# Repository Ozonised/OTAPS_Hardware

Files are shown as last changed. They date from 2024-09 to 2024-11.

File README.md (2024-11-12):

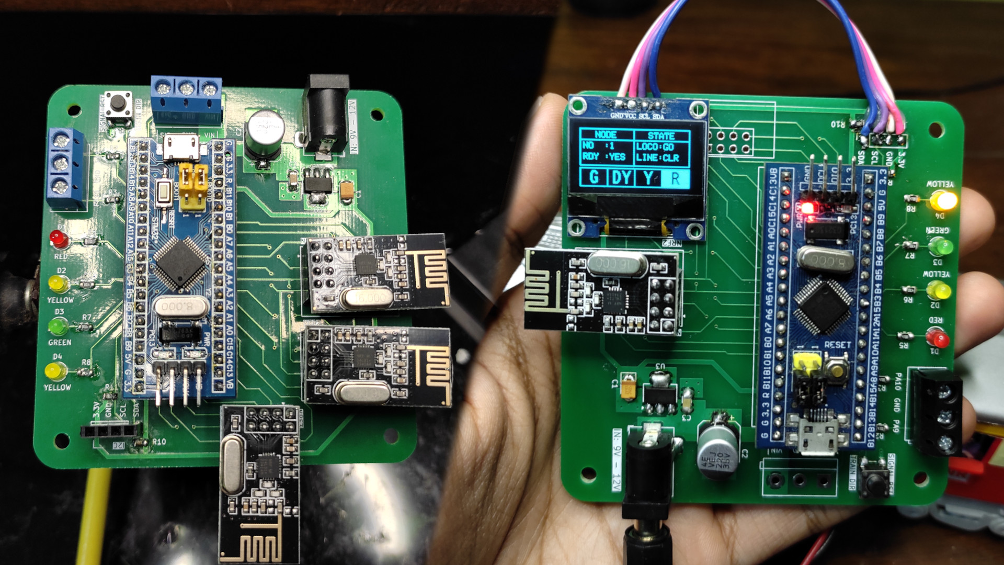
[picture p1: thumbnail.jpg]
thumbnail

# OTAPS - Open Train Accident Prevention System
This repository contains schematic, PCB and wiring files for OTAPS.

## Directory info:
1. ```Wiring``` contains the schematic for wiring signal node.
2. ```WiringLocomotiveUnit``` contains the schematic for wiring the locomotive unit.
3. ```Nodes``` contains the schematic and PCBs files for the PCBs.

# DETAILS:
I created this project for the **Circuit Digest 2024 IoT & Edge AI Project Challenge**.
The firmware for the signal and locomotive units is available at this repository: https://github.com/Ozonised/OTAPS_Firmware
The project details including features, working protocol, build guide and code explanation can be found on this page: https://circuitdigest.com/microcontroller-projects/otaps-open-train-accident-prevention-system

### NOTE:
Both signal and locomotive units utilise the same PCB.

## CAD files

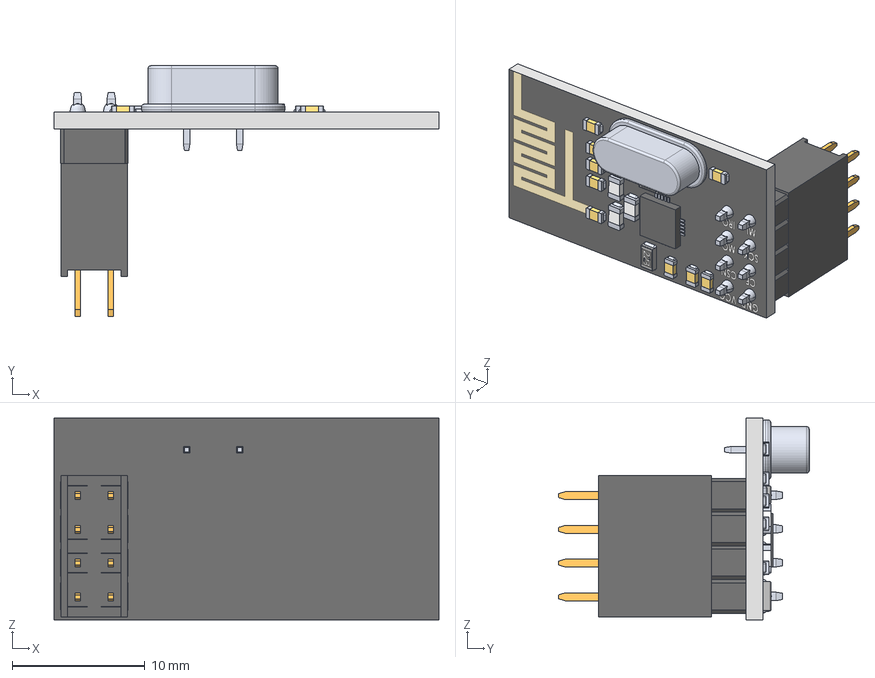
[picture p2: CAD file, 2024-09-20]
Nodes/3D_Models/NRF24L10 with female header-Assembly.step
29.0 x 18.9 x 15.2 mm
nrfboard
CrystalOscillator
doubleMaleHeader x 4
solder x 8
1.7mmSmdCeramicCapacitor x 9
1.7mmSmdCeramicCapacitor001 x 9
1.7mmSmdCeramicCapacitor002 x 9
smdResistor223
smdResistor224
smdResistor225
smdResistor105
smdResistor227
smdResistor228
smdceramiccapacitorwhite x 3
smdceramiccapacitorwhite001 x 3
smdceramiccapacitorwhite002 x 3
4x4SMDchip
4x4SMDchip001
4x4SMDchip002
4x4SMDchip003
4x4SMDchip004
4x4SMDchip005
4x4SMDchip006
4x4SMDchip007
4x4SMDchip008
4x4SMDchip009
4x4SMDchip010
4x4SMDchip011
4x4SMDchip012
4x4SMDchip013
4x4SMDchip014
4x4SMDchip015
4x4SMDchip016
4x4SMDchip017
4x4SMDchip018
4x4SMDchip019
4x4SMDchip020

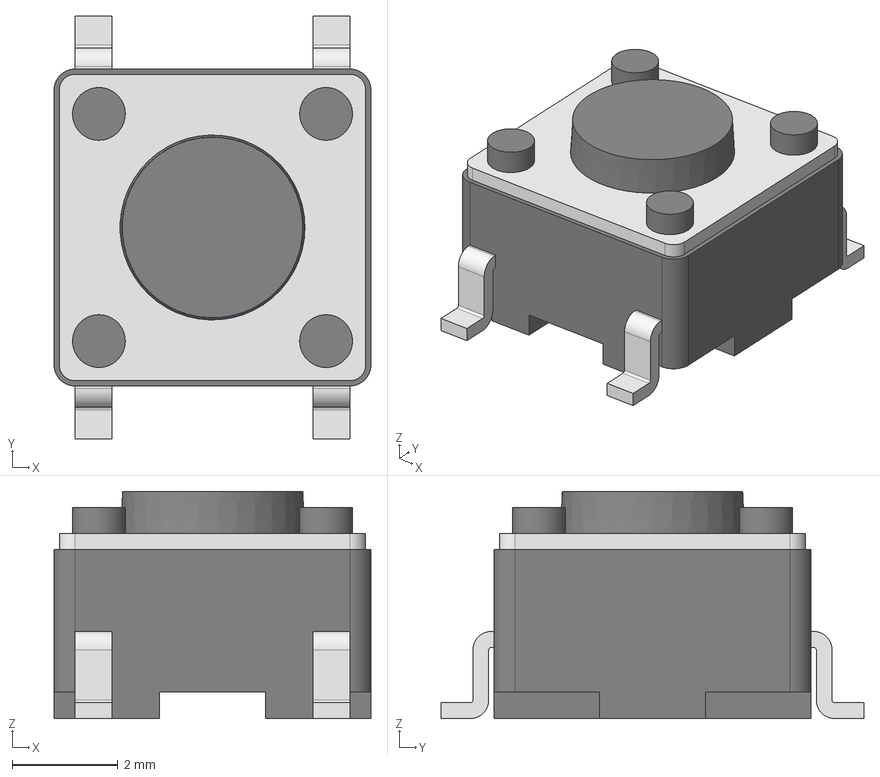
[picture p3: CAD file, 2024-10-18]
Nodes/3D_Models/button_smd_6x6x4.3.stp
6.00 x 8.00 x 4.30 mm

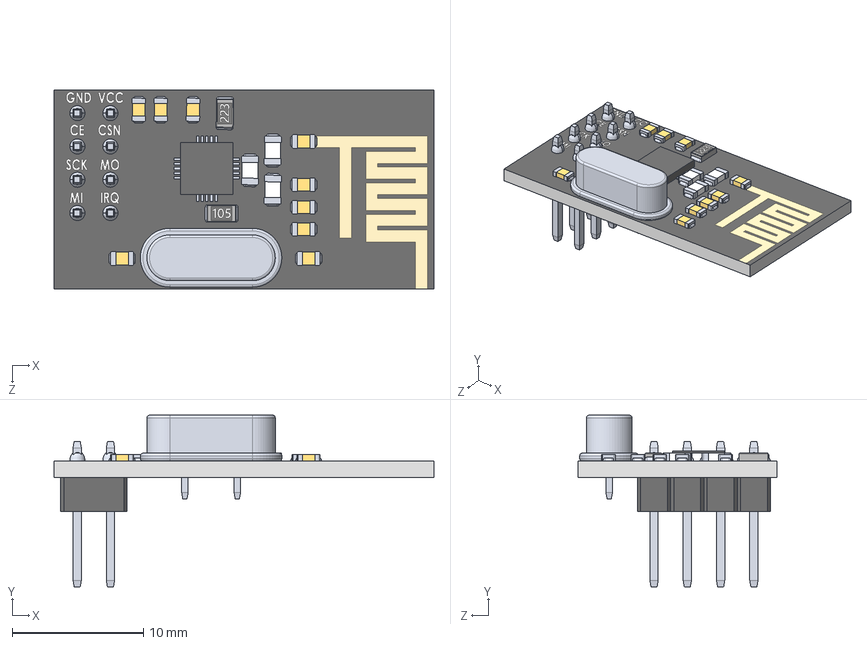
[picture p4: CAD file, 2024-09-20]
Nodes/NRF24/Wireless Radio Transmitter and Receiver nRF24L01.STEP
29.0 x 13.1 x 15.2 mm
nrfboard
CrystalOscillator
doubleMaleHeader x 4
solder x 8
1.7mmSmdCeramicCapacitor x 9
smdResistor223
smdResistor105
smdceramiccapacitorwhite x 3
4x4SMDchip

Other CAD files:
Nodes/3D_Models/3 PIN DG306-5 BLUE - PITCH 5 mm.stp

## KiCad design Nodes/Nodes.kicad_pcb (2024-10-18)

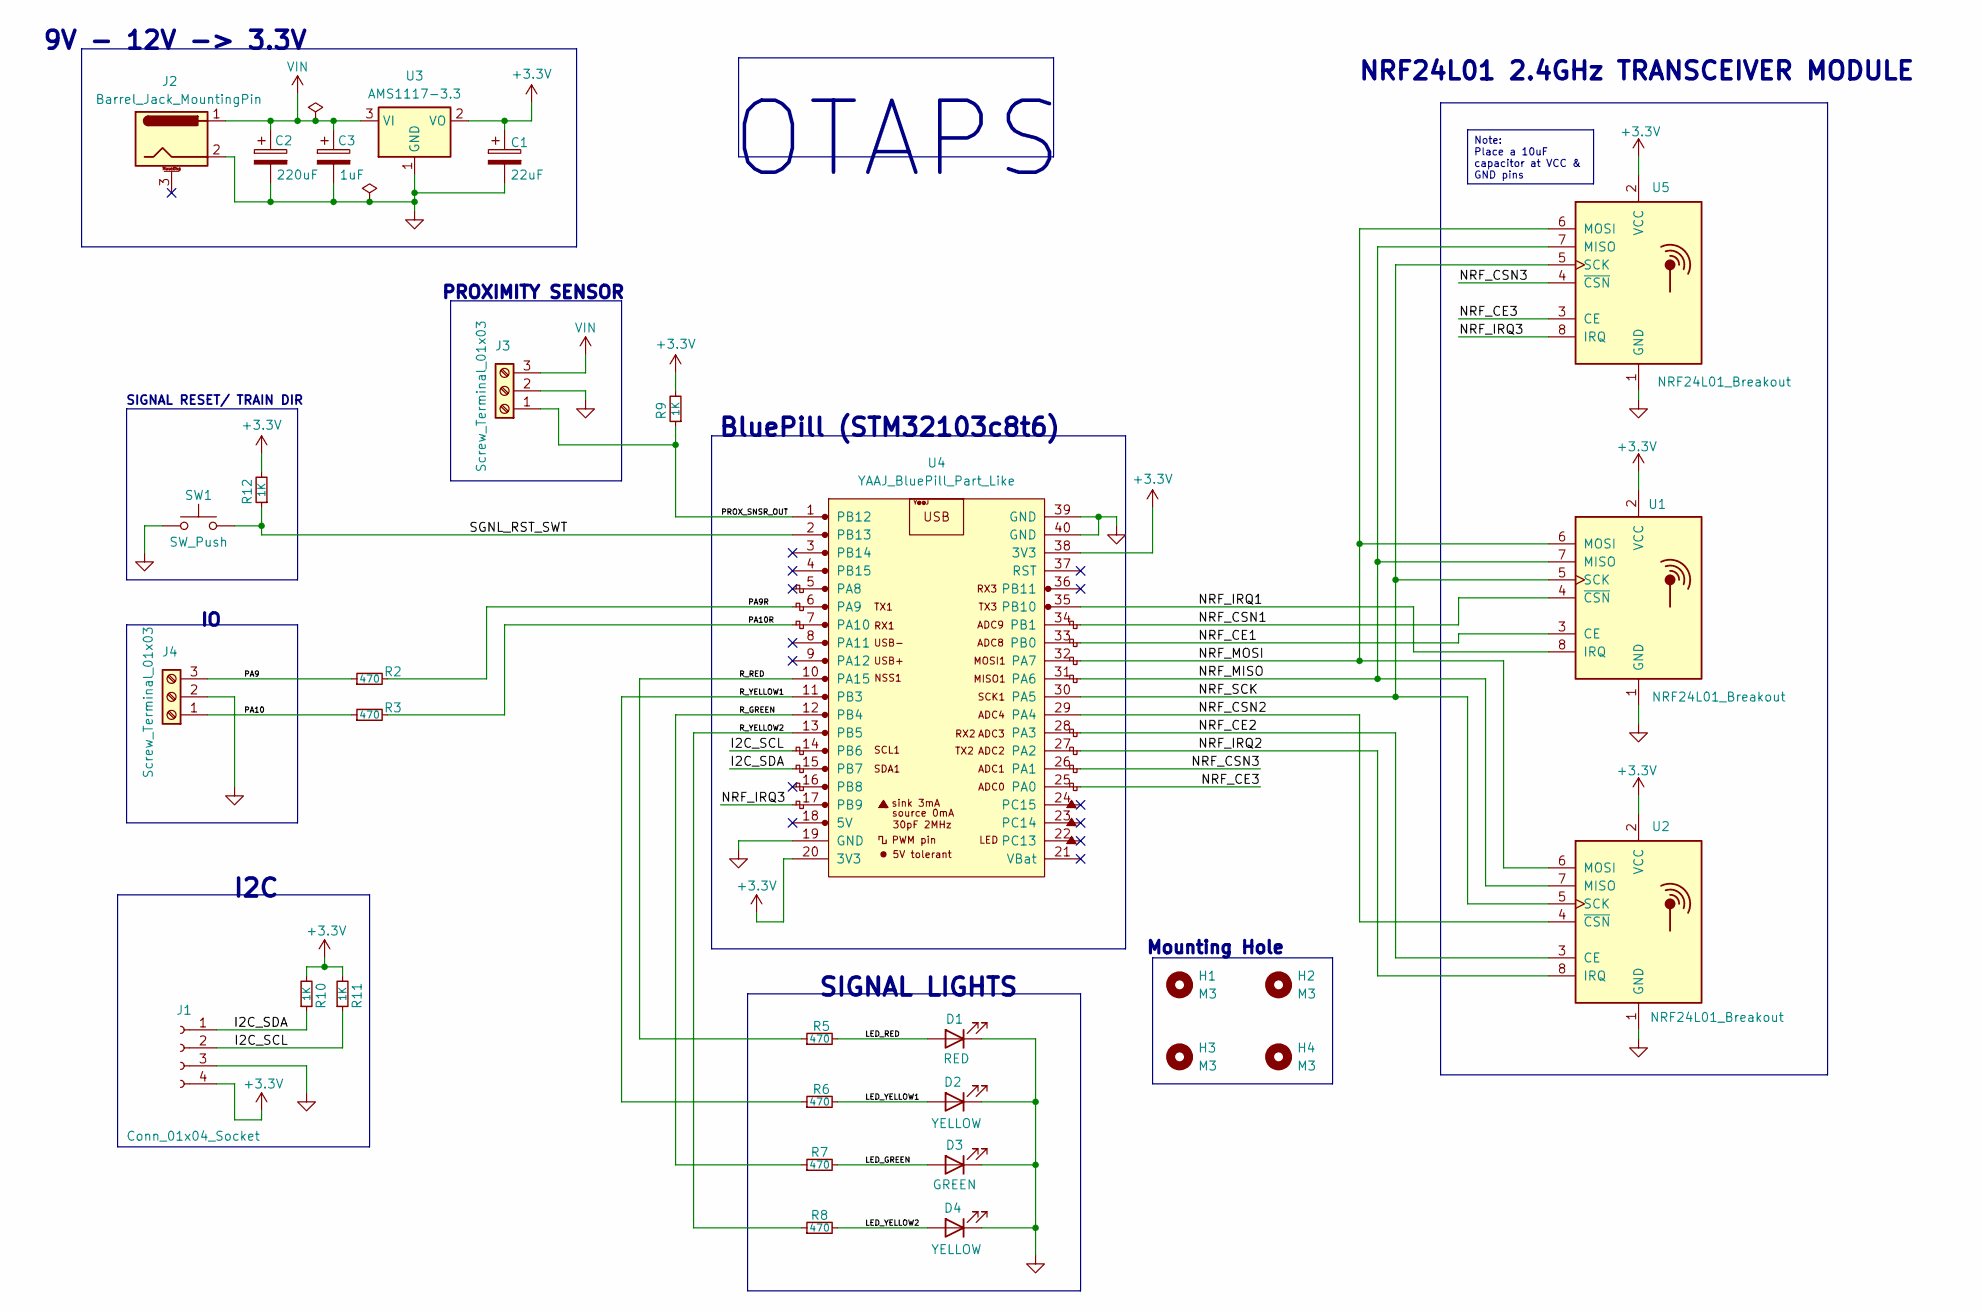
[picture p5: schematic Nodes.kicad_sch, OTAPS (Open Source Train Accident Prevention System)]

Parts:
C1: 22uF; CP_EIA-3528-15_AVX-H_Pad1.50x2.35mm_HandSolder
C2: 220uF; CP_Elec_8x10.5
C3: 1uF; C_1206_3216Metric_Pad1.33x1.80mm_HandSolder
D1: RED; LED_D3.0mm
D2, D4: YELLOW; LED_D3.0mm
D3: GREEN; LED_D3.0mm
H1, H2, H3, H4: M3; MountingHole_3.2mm_M3
J1: Conn_01x04_Socket; PinSocket_1x04_P2.54mm_Vertical
J2: Barrel_Jack_MountingPin; BarrelJack_Horizontal
J3, J4: Screw_Terminal_01x03
R2, R3, R5, R6, R7, R8: 470; R_0805_2012Metric_Pad1.20x1.40mm_HandSolder
R9, R10, R11, R12: 1K; R_0805_2012Metric_Pad1.20x1.40mm_HandSolder
SW1: SW_Push; SW_SPST_PTS647_Sx38
U1, U2, U5: NRF24L01_Breakout; nRF24L01_Breakout
U3: AMS1117-3.3; SOT-223-3_TabPin2
U4: YAAJ_BluePill_Part_Like; YAAJ_BluePill_1

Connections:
+3.3V: C1.1, J1.4, R9.2, R10.2, R11.2, R12.2, U1.2 (VCC), U2.2 (VCC), U3.2 (VO), U4.20 (3V3), U4.38 (3V3), U5.2 (VCC)
/I2C_SCL: J1.2, R11.1, U4.14 (PB6)
/I2C_SDA: J1.1, R10.1, U4.15 (PB7)
/LED_GREEN: D3.2 (A), R7.2
/LED_RED: D1.2 (A), R5.2
/LED_YELLOW1: D2.2 (A), R6.2
/LED_YELLOW2: D4.2 (A), R8.2
/NRF_CE1: U1.3 (CE), U4.33 (PB0)
/NRF_CE2: U2.3 (CE), U4.28 (PA3)
/NRF_CE3: U4.25 (PA0), U5.3 (CE)
/NRF_CSN1: U1.4 (~CSN), U4.34 (PB1)
/NRF_CSN2: U2.4 (~CSN), U4.29 (PA4)
/NRF_CSN3: U4.26 (PA1), U5.4 (~CSN)
/NRF_IRQ1: U1.8 (IRQ), U4.35 (PB10)
/NRF_IRQ2: U2.8 (IRQ), U4.27 (PA2)
/NRF_IRQ3: U4.17 (PB9), U5.8 (IRQ)
/NRF_MISO: U1.7 (MISO), U2.7 (MISO), U4.31 (PA6), U5.7 (MISO)
/NRF_MOSI: U1.6 (MOSI), U2.6 (MOSI), U4.32 (PA7), U5.6 (MOSI)
/NRF_SCK: U1.5 (SCK), U2.5 (SCK), U4.30 (PA5), U5.5 (SCK)
/PA9: J4.3, R2.1
/PA9R: R2.2, U4.6 (PA9)
/PA10: J4.1, R3.1
/PA10R: R3.2, U4.7 (PA10)
/PROX_SNSR_OUT: J3.1, R9.1, U4.1 (PB12)
/R_GREEN: R7.1, U4.12 (PB4)
/R_RED: R5.1, U4.10 (PA15)
/R_YELLOW1: R6.1, U4.11 (PB3)
/R_YELLOW2: R8.1, U4.13 (PB5)
/SGNL_RST_SWT: R12.1, SW1.2, U4.2 (PB13)
GND: C1.2, C2.2, C3.2, D1.1 (K), D2.1 (K), D3.1 (K), D4.1 (K), J1.3, J2.2, J3.2, J4.2, SW1.1, U1.1 (GND), U2.1 (GND), U3.1 (GND), U4.19 (GND), U4.39 (GND), U4.40 (GND), U5.1 (GND)
VIN: C2.1, C3.1, J2.1, J3.3, U3.3 (VI)

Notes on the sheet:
Note: Place a 10uF capacitor at VCC & GND pins
NRF24L01 2.4GHz TRANSCEIVER MODULE
SIGNAL LIGHTS
9V - 12V -> 3.3V
I2C
BluePill (STM32103c8t6)
OTAPS
Mounting Hole
PROXIMITY SENSOR
SIGNAL RESET/ TRAIN DIR

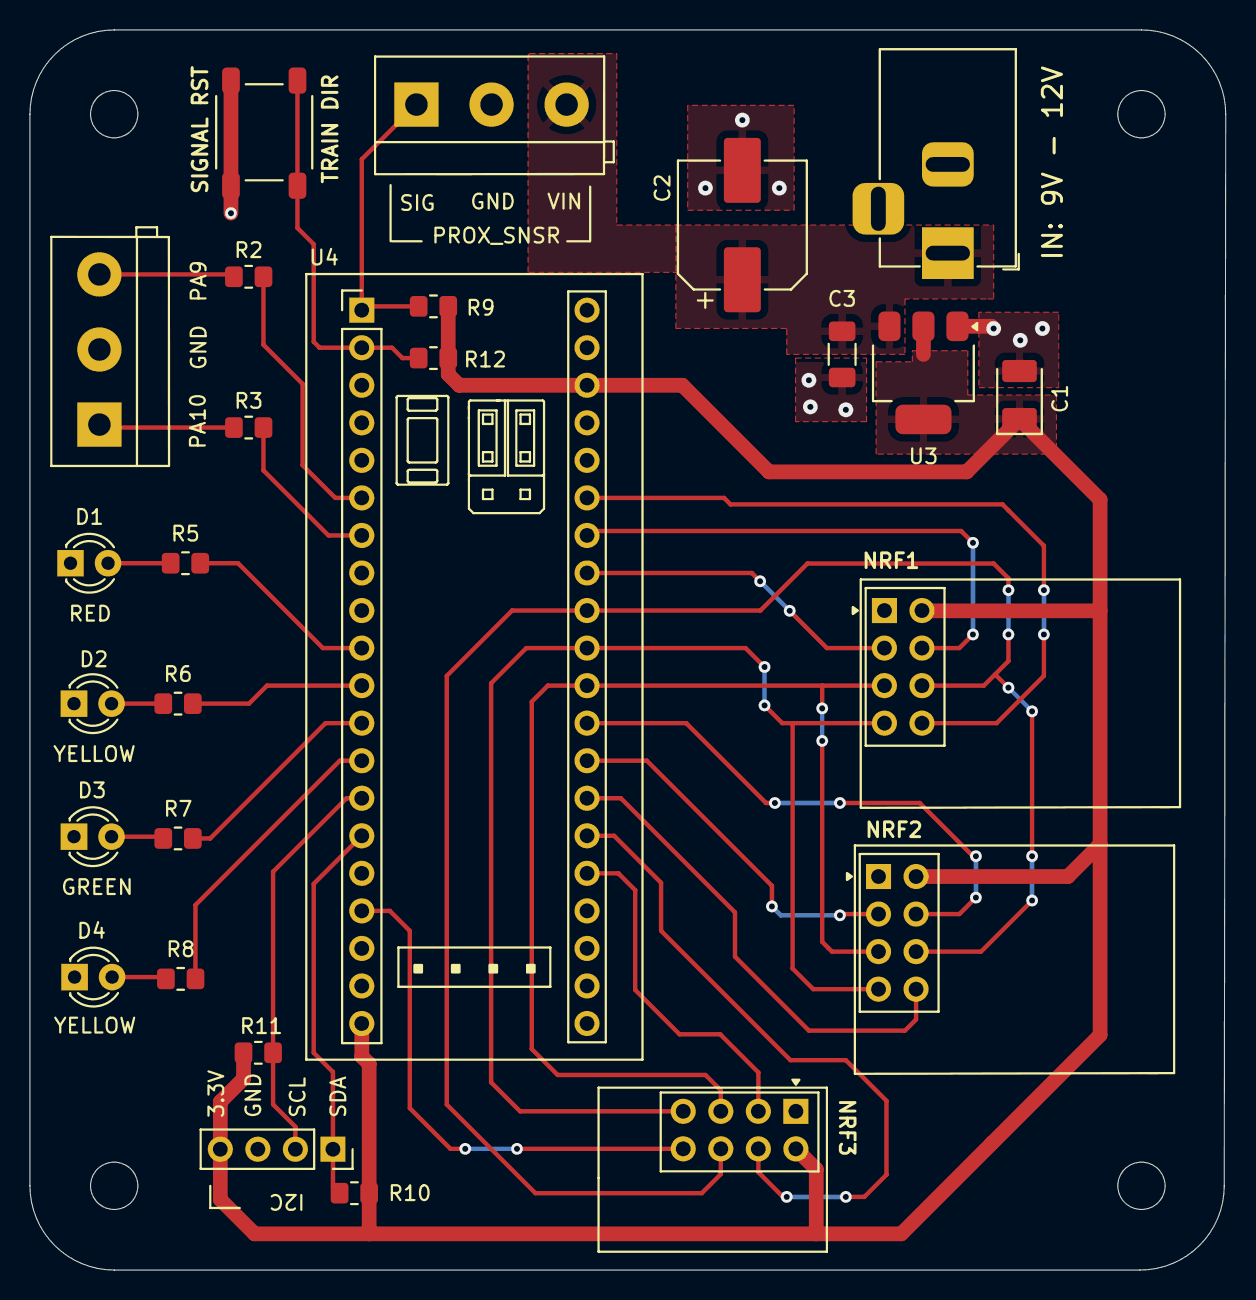
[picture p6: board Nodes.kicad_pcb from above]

Board: 2 copper layers, 80.9 x 83.9 mm, 31 parts (0 on the bottom side), 31 nets.

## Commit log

2024-09-20 chore: initial commit
    [3 PIN DG306-5 BLUE - PITCH 5 mm.stp, NRF24L10 with female header-Assembly.step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]
2024-09-20 chore: update GitHub repository path
    [Nodes.kicad_pcb, Nodes.kicad_sch]
2024-09-20 chore: add author, licensce and GitHub repository info
    [Wiring.kicad_sch, WiringLocomotiveUnit.kicad_sch]
2024-09-20 fix: remove 3.3V connection between arduino & signal node
    The signal node and the arduino should be powered from the barrel connector.
    Also added a note regarding this to the schematic.
    [Wiring.kicad_sch]
2024-09-20 fix: update the node schematic symbol as per rev 1.1
    [Wiring.kicad_sch, WiringLocomotiveUnit.kicad_sch]
2024-09-21 chore: add labels to switch
    rename OLED port on pcb to I2C, added "TRAIN DIR" text to switch on schematic and PCB.
    [Nodes.kicad_pcb, Nodes.kicad_sch]
2024-09-25 chore: change connections for NRF24(U5), IO port and LEDs
    [Nodes.kicad_pcb, Nodes.kicad_sch]
2024-09-27 fix: change silkscreen line width to 0.152 and update vendor link for resistors and NRF24
    [Nodes-B_Cu.gbl, Nodes-B_Mask.gbs, Nodes-B_Paste.gbp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]
2024-10-02 docs: add details section
    add links to firmware repo and the circuit digest project page
2024-10-18 fix: change switch footprint changed the switch footprint and associated 3D model regenerated the gerbers
    [Nodes-B_Cu.gbl, Nodes-B_Mask.gbs, Nodes-B_Paste.gbp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]

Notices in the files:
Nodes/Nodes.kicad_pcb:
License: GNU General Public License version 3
